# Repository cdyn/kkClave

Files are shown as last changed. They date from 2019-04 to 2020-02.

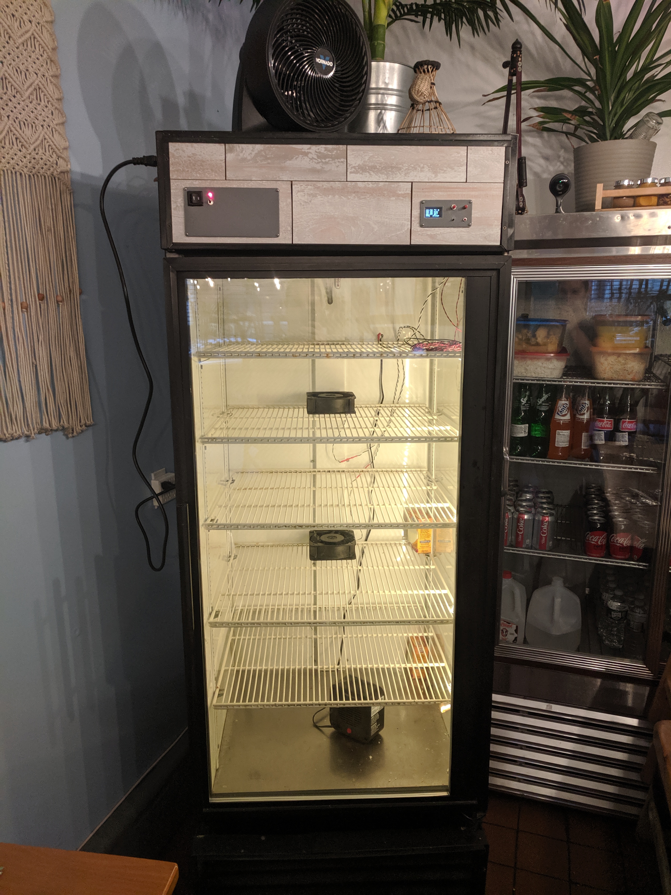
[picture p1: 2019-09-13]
images/kkClave_testFit.jpg

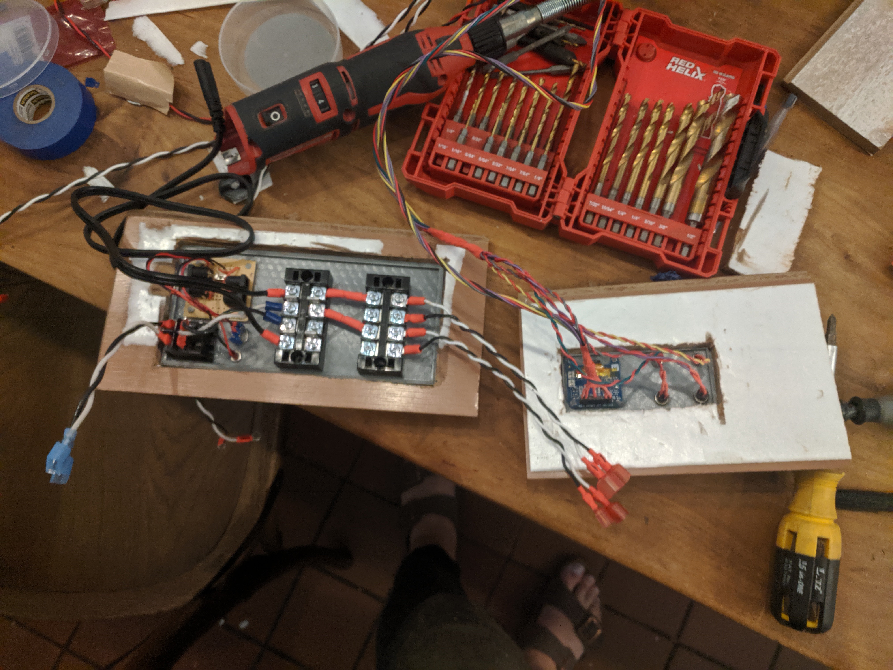
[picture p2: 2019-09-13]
images/kkClave_panels.jpg

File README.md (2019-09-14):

# kkClave ([wiki](https://github.com/cdyn/kkClave/wiki))
## [Korai Kitchen](https://www.koraikitchen.com/) Clave for yogurt incubation
#### Designed by [Jean Runnells](https://github.com/JERiv) @ [CDYN](https://github.com/cdyn)

This is a simple yougurt incubator that uses an arduino mega, a relay shield, and a space heater to make doi (yogurt) on a large scale in an upcycled beverege fridge. In this repository are: 
* [Fusion 360](../master/fusion) drawings for the power supply panel, the front panel, and an enclosure.
* [Eagle](../master/eagle) sketch of basic circuit diagram for logic and power supply including relevant shields
* [Arduino](../master/arduino) main program code

## See the [wiki](https://github.com/cdyn/kkClave/wiki) for installtion, fabrication, and use details.

## TODO:
*  implement ethernet
*  add cooling cycle features
*  handle clock overflow

[**Custom Dynamics**](https://www.customdyn.com) © [*GNU General Public License v3.0*](https://github.com/cdyn/kkClave/blob/master/LICENSE)

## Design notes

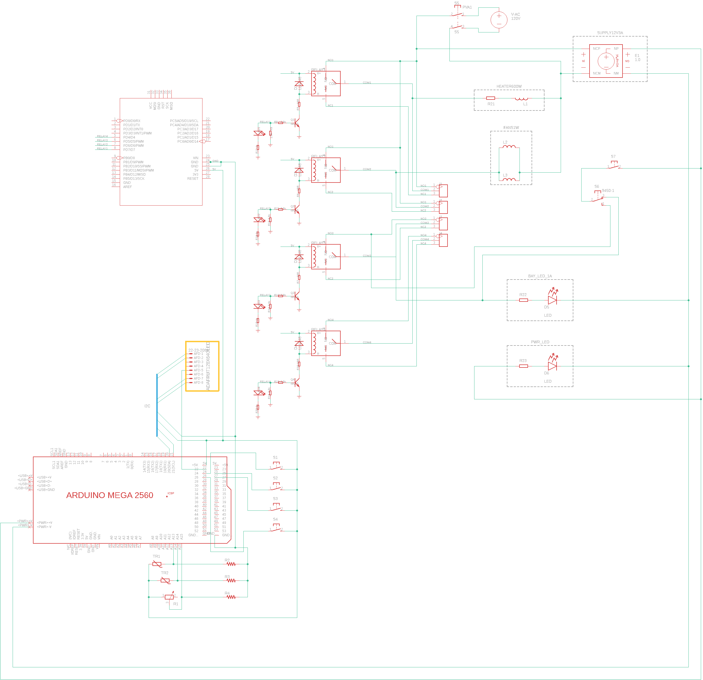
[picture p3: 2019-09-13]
images/kkClave_circuit.png

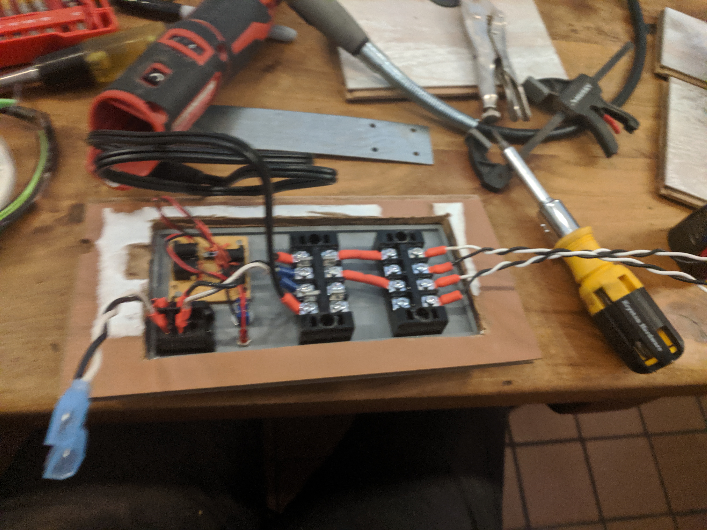
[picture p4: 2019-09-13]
images/kkClave_pwrPanel.jpg

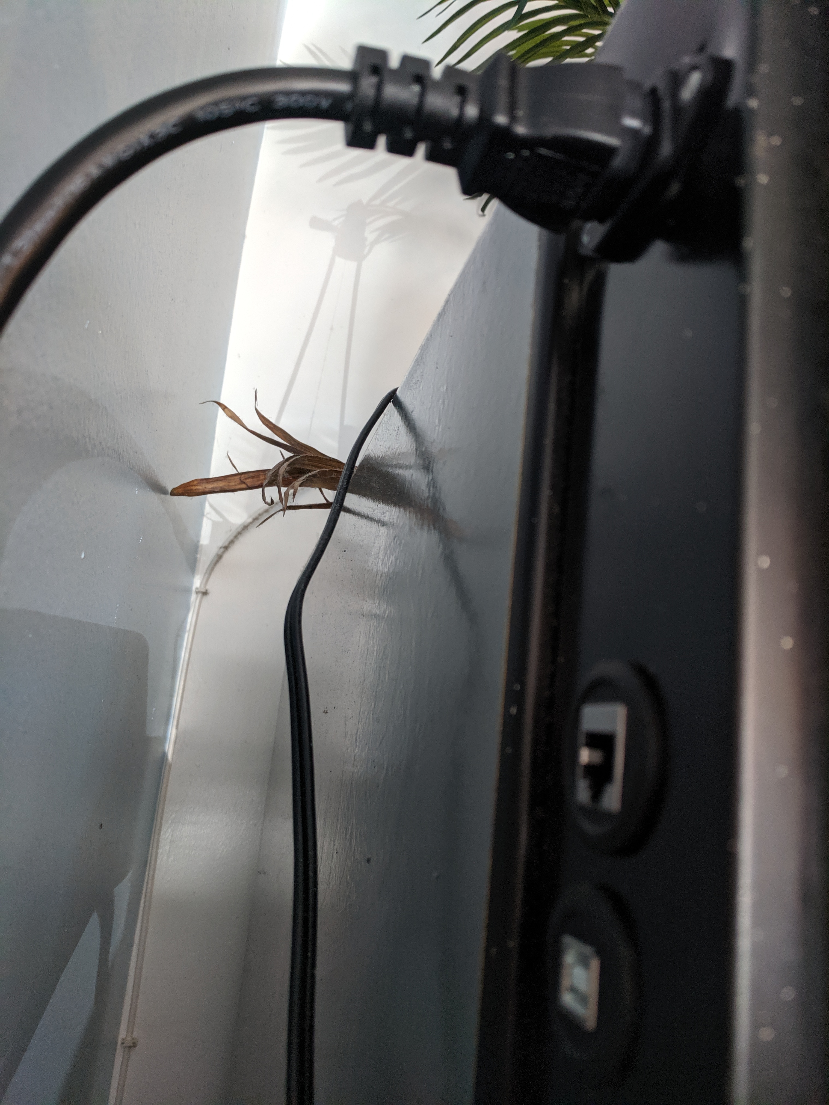
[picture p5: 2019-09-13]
images/kkClave_sidePlane.jpg

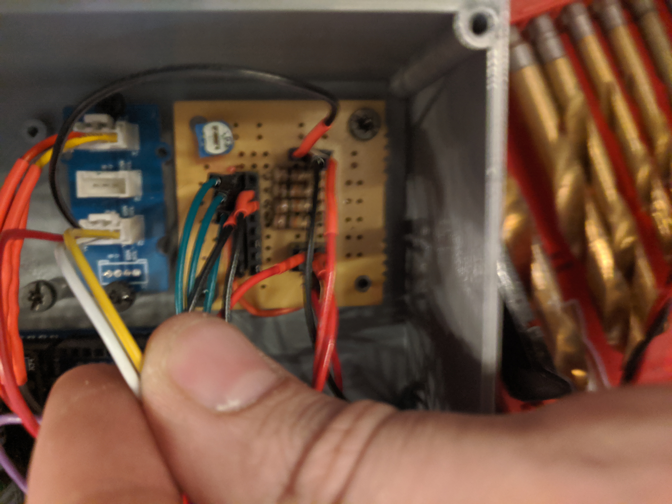
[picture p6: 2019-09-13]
images/kkClave_thermistorI2Cbreakout.jpg

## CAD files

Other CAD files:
fusion/kkClave_Front_Panel v1.f3d
fusion/kkClave_Logic_Enclosure.f3d
fusion/kkClave_Power_Panel v7.f3d

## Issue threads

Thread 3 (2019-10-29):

Logic reset

JERiv, 2019-10-29:
Leak through current from the ac supply is resetting the logic board particularly after the clave has warmed up, hopefully not heat and just requires a snubber to protect against transient voltage spikes

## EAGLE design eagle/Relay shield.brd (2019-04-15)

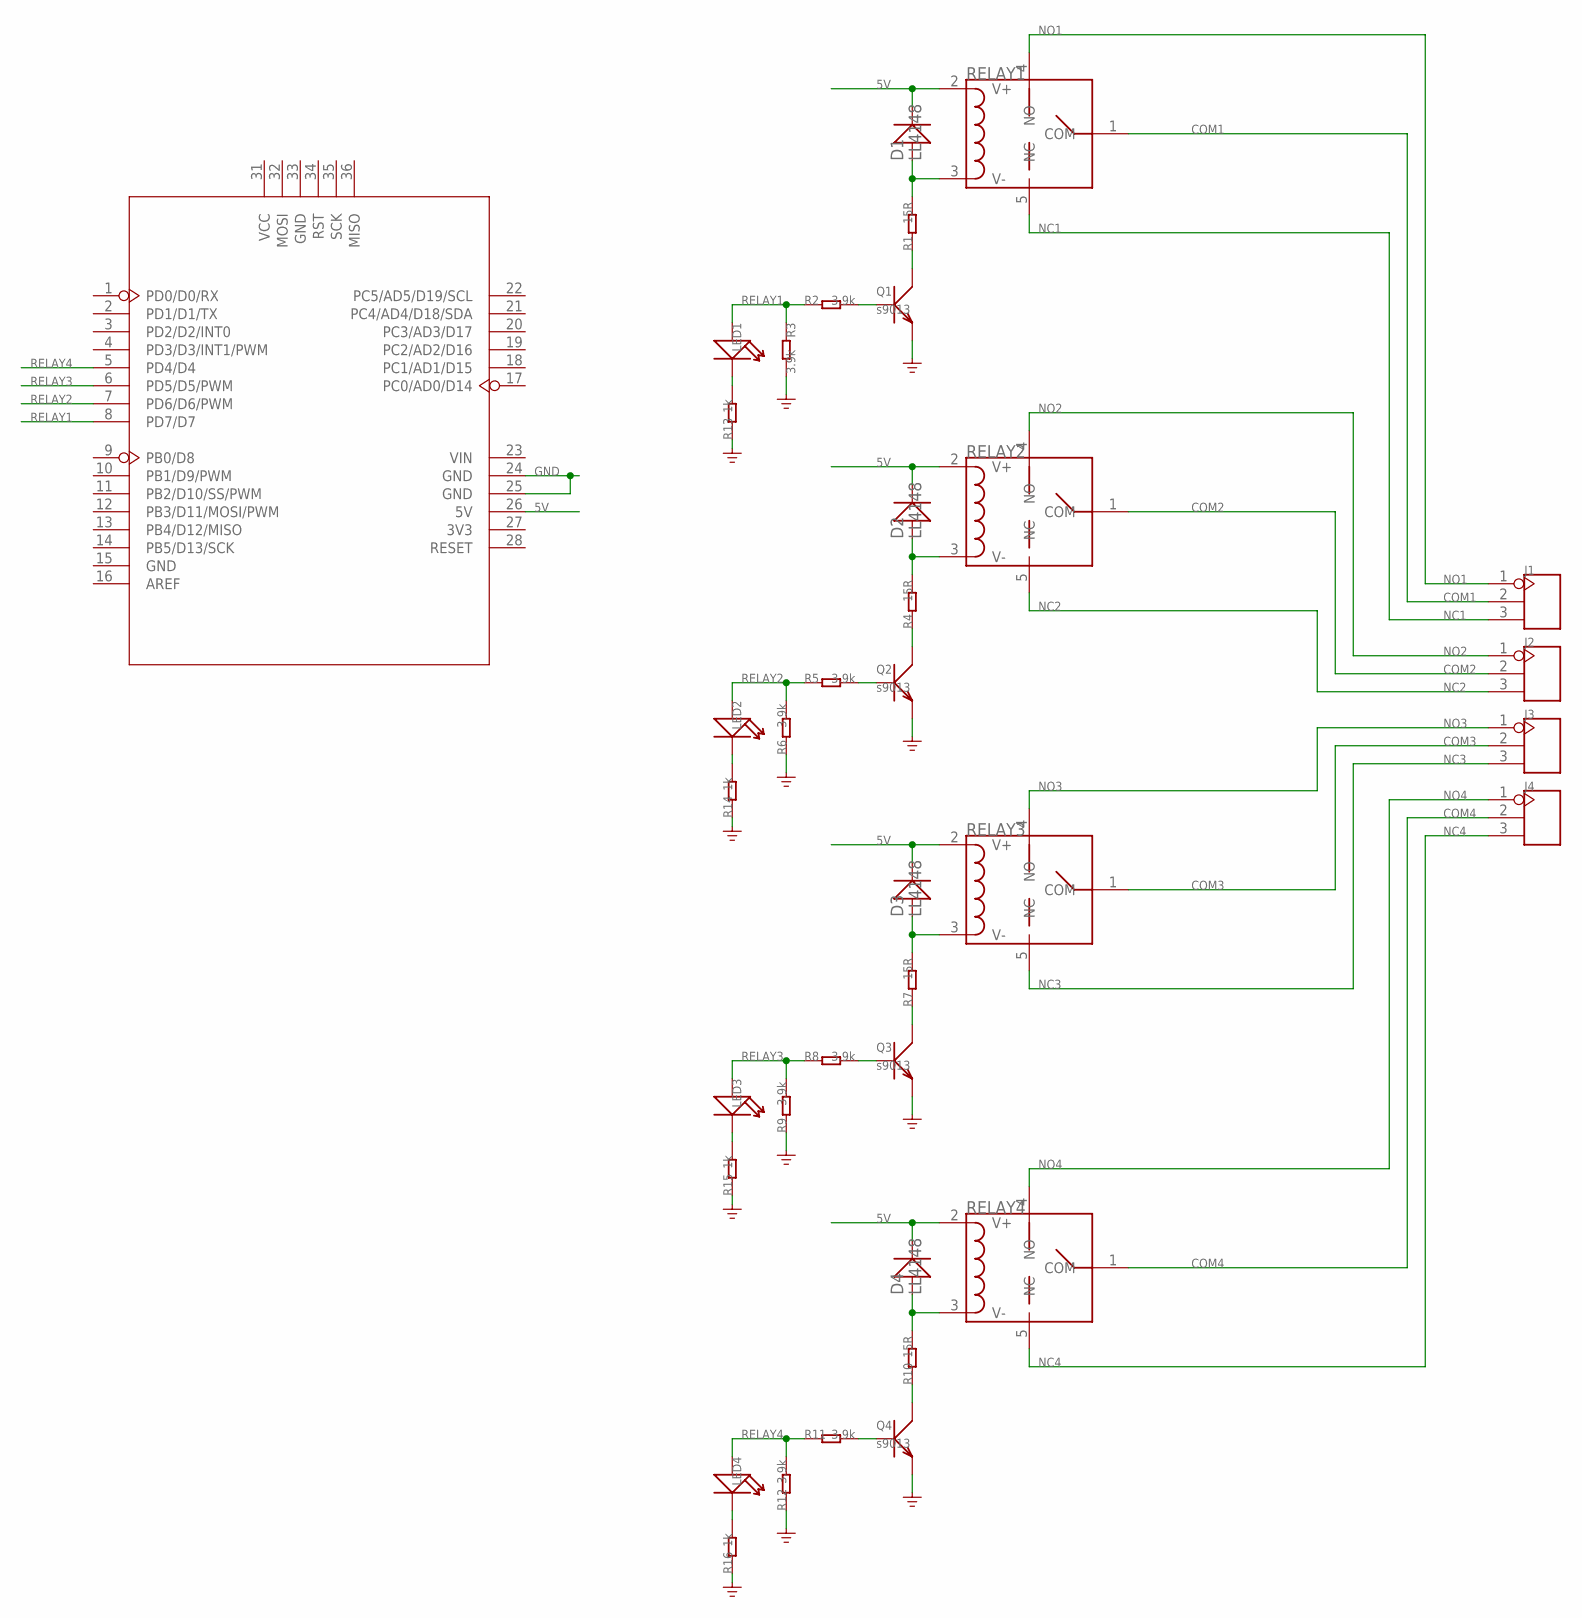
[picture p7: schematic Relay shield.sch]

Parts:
D1, D2, D3, D4: LL4148; D1206
J1, J2, J3, J4: SCREW-TERMINAL-3P'5.08'; 3P-5.08
LED1, LED2, LED3, LED4: LED'0603'; LED-0603
Q1, Q2, Q3, Q4: s9013; SOT23
R1, R4, R7, R10: 15R; R0603
R2, R3, R5, R6, R8, R9, R11, R12: 3.9k; R0603
R13, R14, R15, R16: 1k; R0603
RELAY1, RELAY2, RELAY3, RELAY4: RELAY-HLS8L-DC5V-S-C; 5P-19.0X15.5X15.8H
U1: ARDUINO'W/O-SILK'; ARDUINO-W/O-SILK

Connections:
5V: D1.-, D2.-, D3.-, D4.-, RELAY1.2 (V+), RELAY2.2 (V+), RELAY3.2 (V+), RELAY4.2 (V+), U1.26 (5V)
COM1: J1.2, RELAY1.1 (COM)
COM2: J2.2, RELAY2.1 (COM)
COM3: J3.2, RELAY3.1 (COM)
COM4: J4.2, RELAY4.1 (COM)
GND: Q1.2 (E), Q2.2 (E), Q3.2 (E), Q4.2 (E), R3.2, R6.1, R9.1, R12.1, R13.1, R14.1, R15.1, R16.1, U1.24 (GND), U1.25 (GND)
unnamed: D2.+, R4.2, RELAY2.3 (V-)
unnamed: D3.+, R7.2, RELAY3.3 (V-)
unnamed: D4.+, R10.2, RELAY4.3 (V-)
unnamed: Q1.3 (C), R1.1
unnamed: Q2.3 (C), R4.1
unnamed: Q4.1 (B), R11.2
unnamed: D1.+, R1.2, RELAY1.3 (V-)
unnamed: Q3.3 (C), R7.1
unnamed: Q4.3 (C), R10.1
unnamed: Q3.1 (B), R8.2
unnamed: LED1.-, R13.2
unnamed: LED2.-, R14.2
unnamed: LED3.-, R15.2
unnamed: LED4.-, R16.2
unnamed: Q2.1 (B), R5.2
unnamed: Q1.1 (B), R2.2
NC1: J1.3, RELAY1.5 (NC)
NC2: J2.3, RELAY2.5 (NC)
NC3: J3.3, RELAY3.5 (NC)
NC4: J4.3, RELAY4.5 (NC)
NO1: J1.1, RELAY1.4 (NO)
NO2: J2.1, RELAY2.4 (NO)
NO3: J3.1, RELAY3.4 (NO)
NO4: J4.1, RELAY4.4 (NO)
RELAY1: LED1.+, R2.1, R3.1, U1.8 (PD7/D7)
RELAY2: LED2.+, R5.1, R6.2, U1.7 (PD6/D6/PWM)
RELAY3: LED3.+, R8.1, R9.2, U1.6 (PD5/D5/PWM)
RELAY4: LED4.+, R11.1, R12.2, U1.5 (PD4/D4)

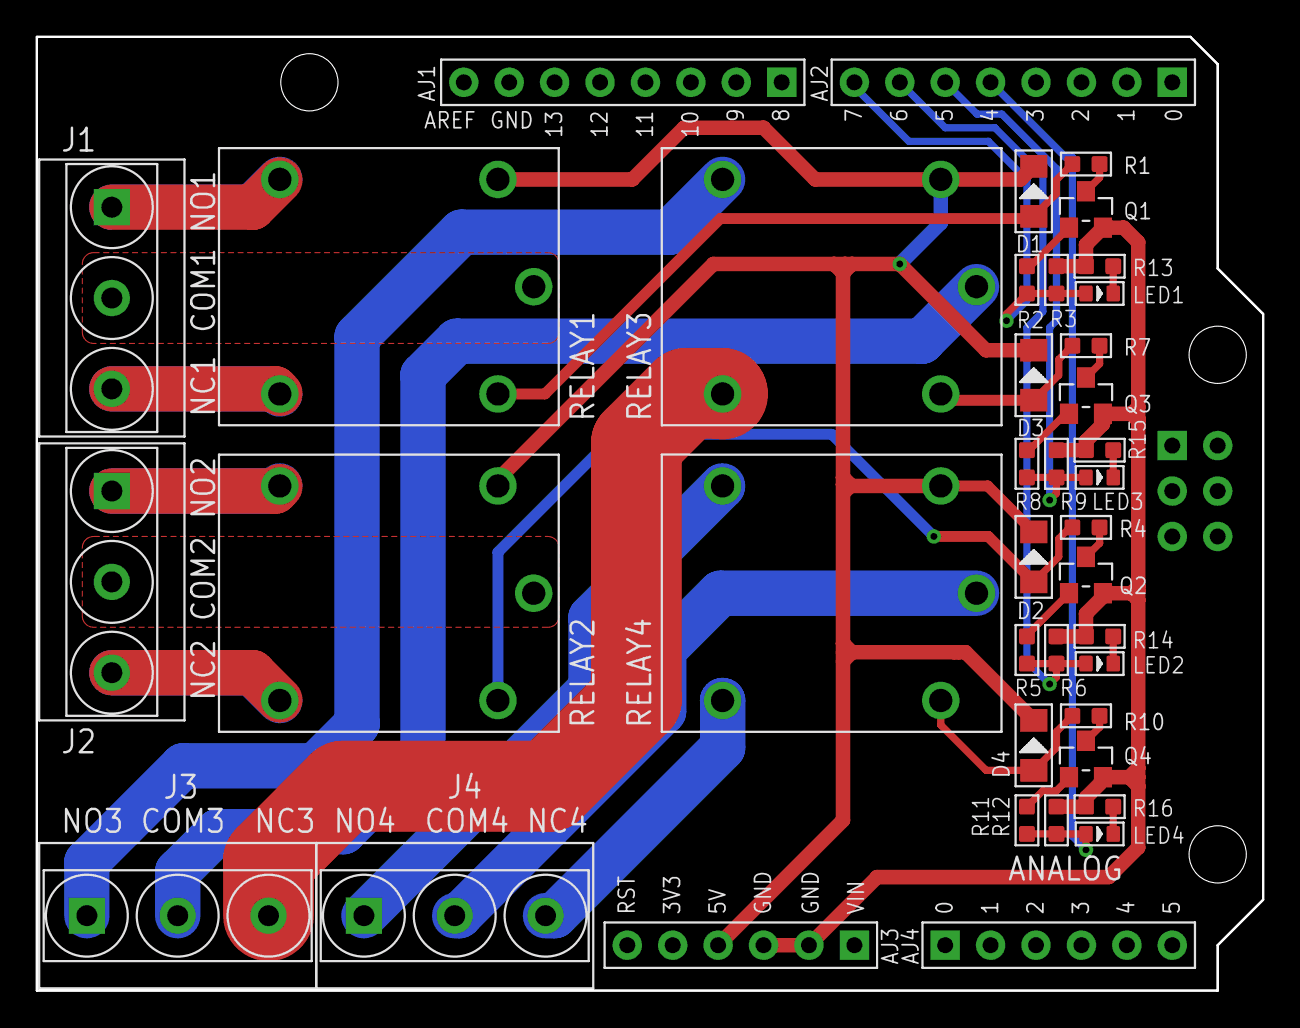
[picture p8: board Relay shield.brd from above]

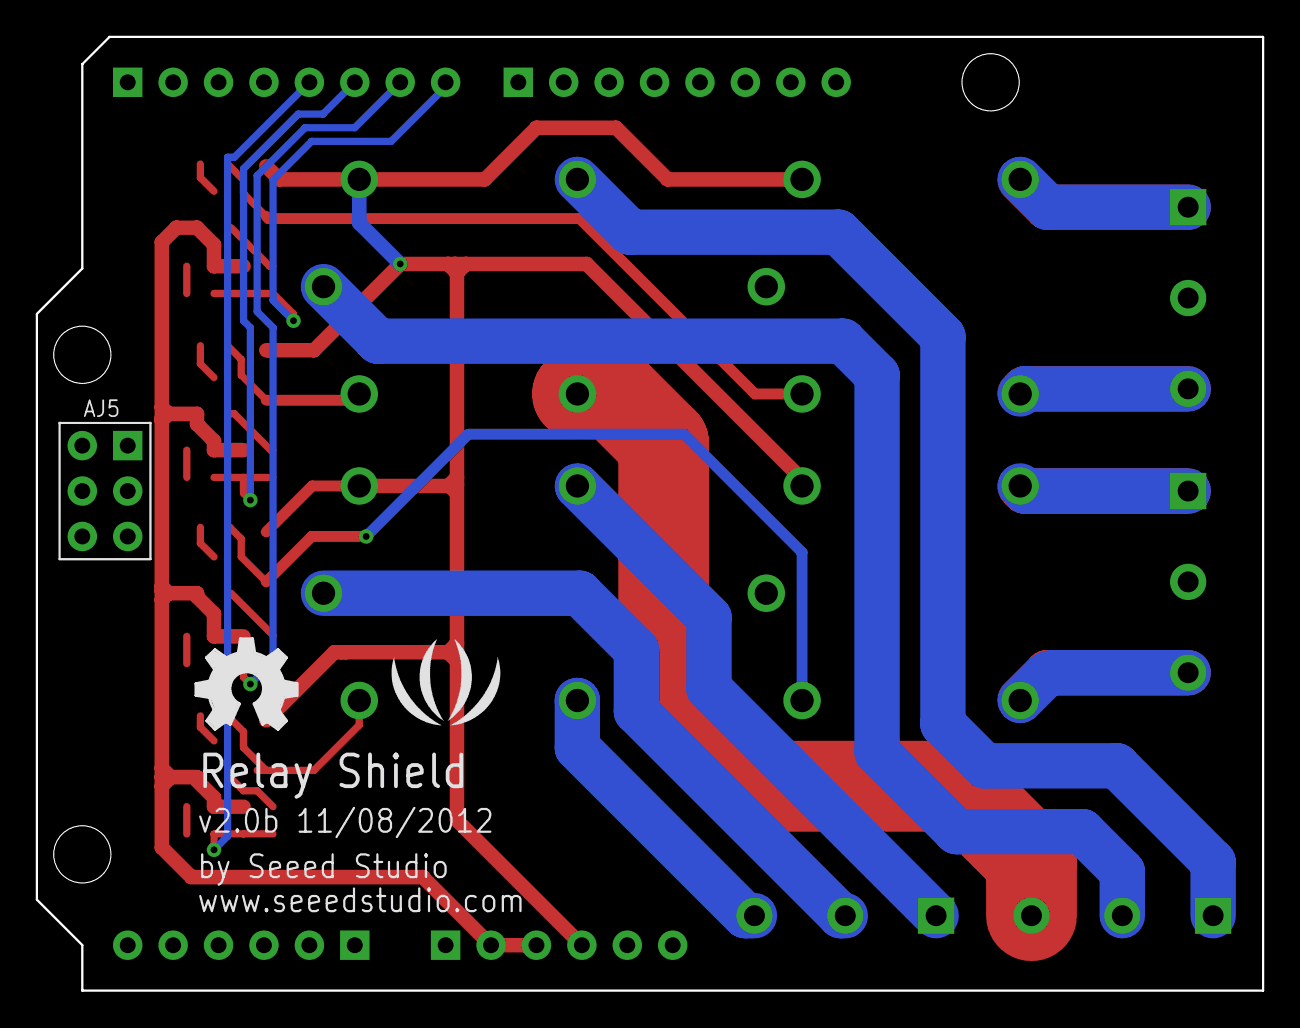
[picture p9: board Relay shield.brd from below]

Board: 2 copper layers, 68.6 x 53.3 mm, 39 parts (2 on the bottom side), 34 nets.

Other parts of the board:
U$13: LOGO_SILK
U$14: OSHW_FILLX200_NOTEXT

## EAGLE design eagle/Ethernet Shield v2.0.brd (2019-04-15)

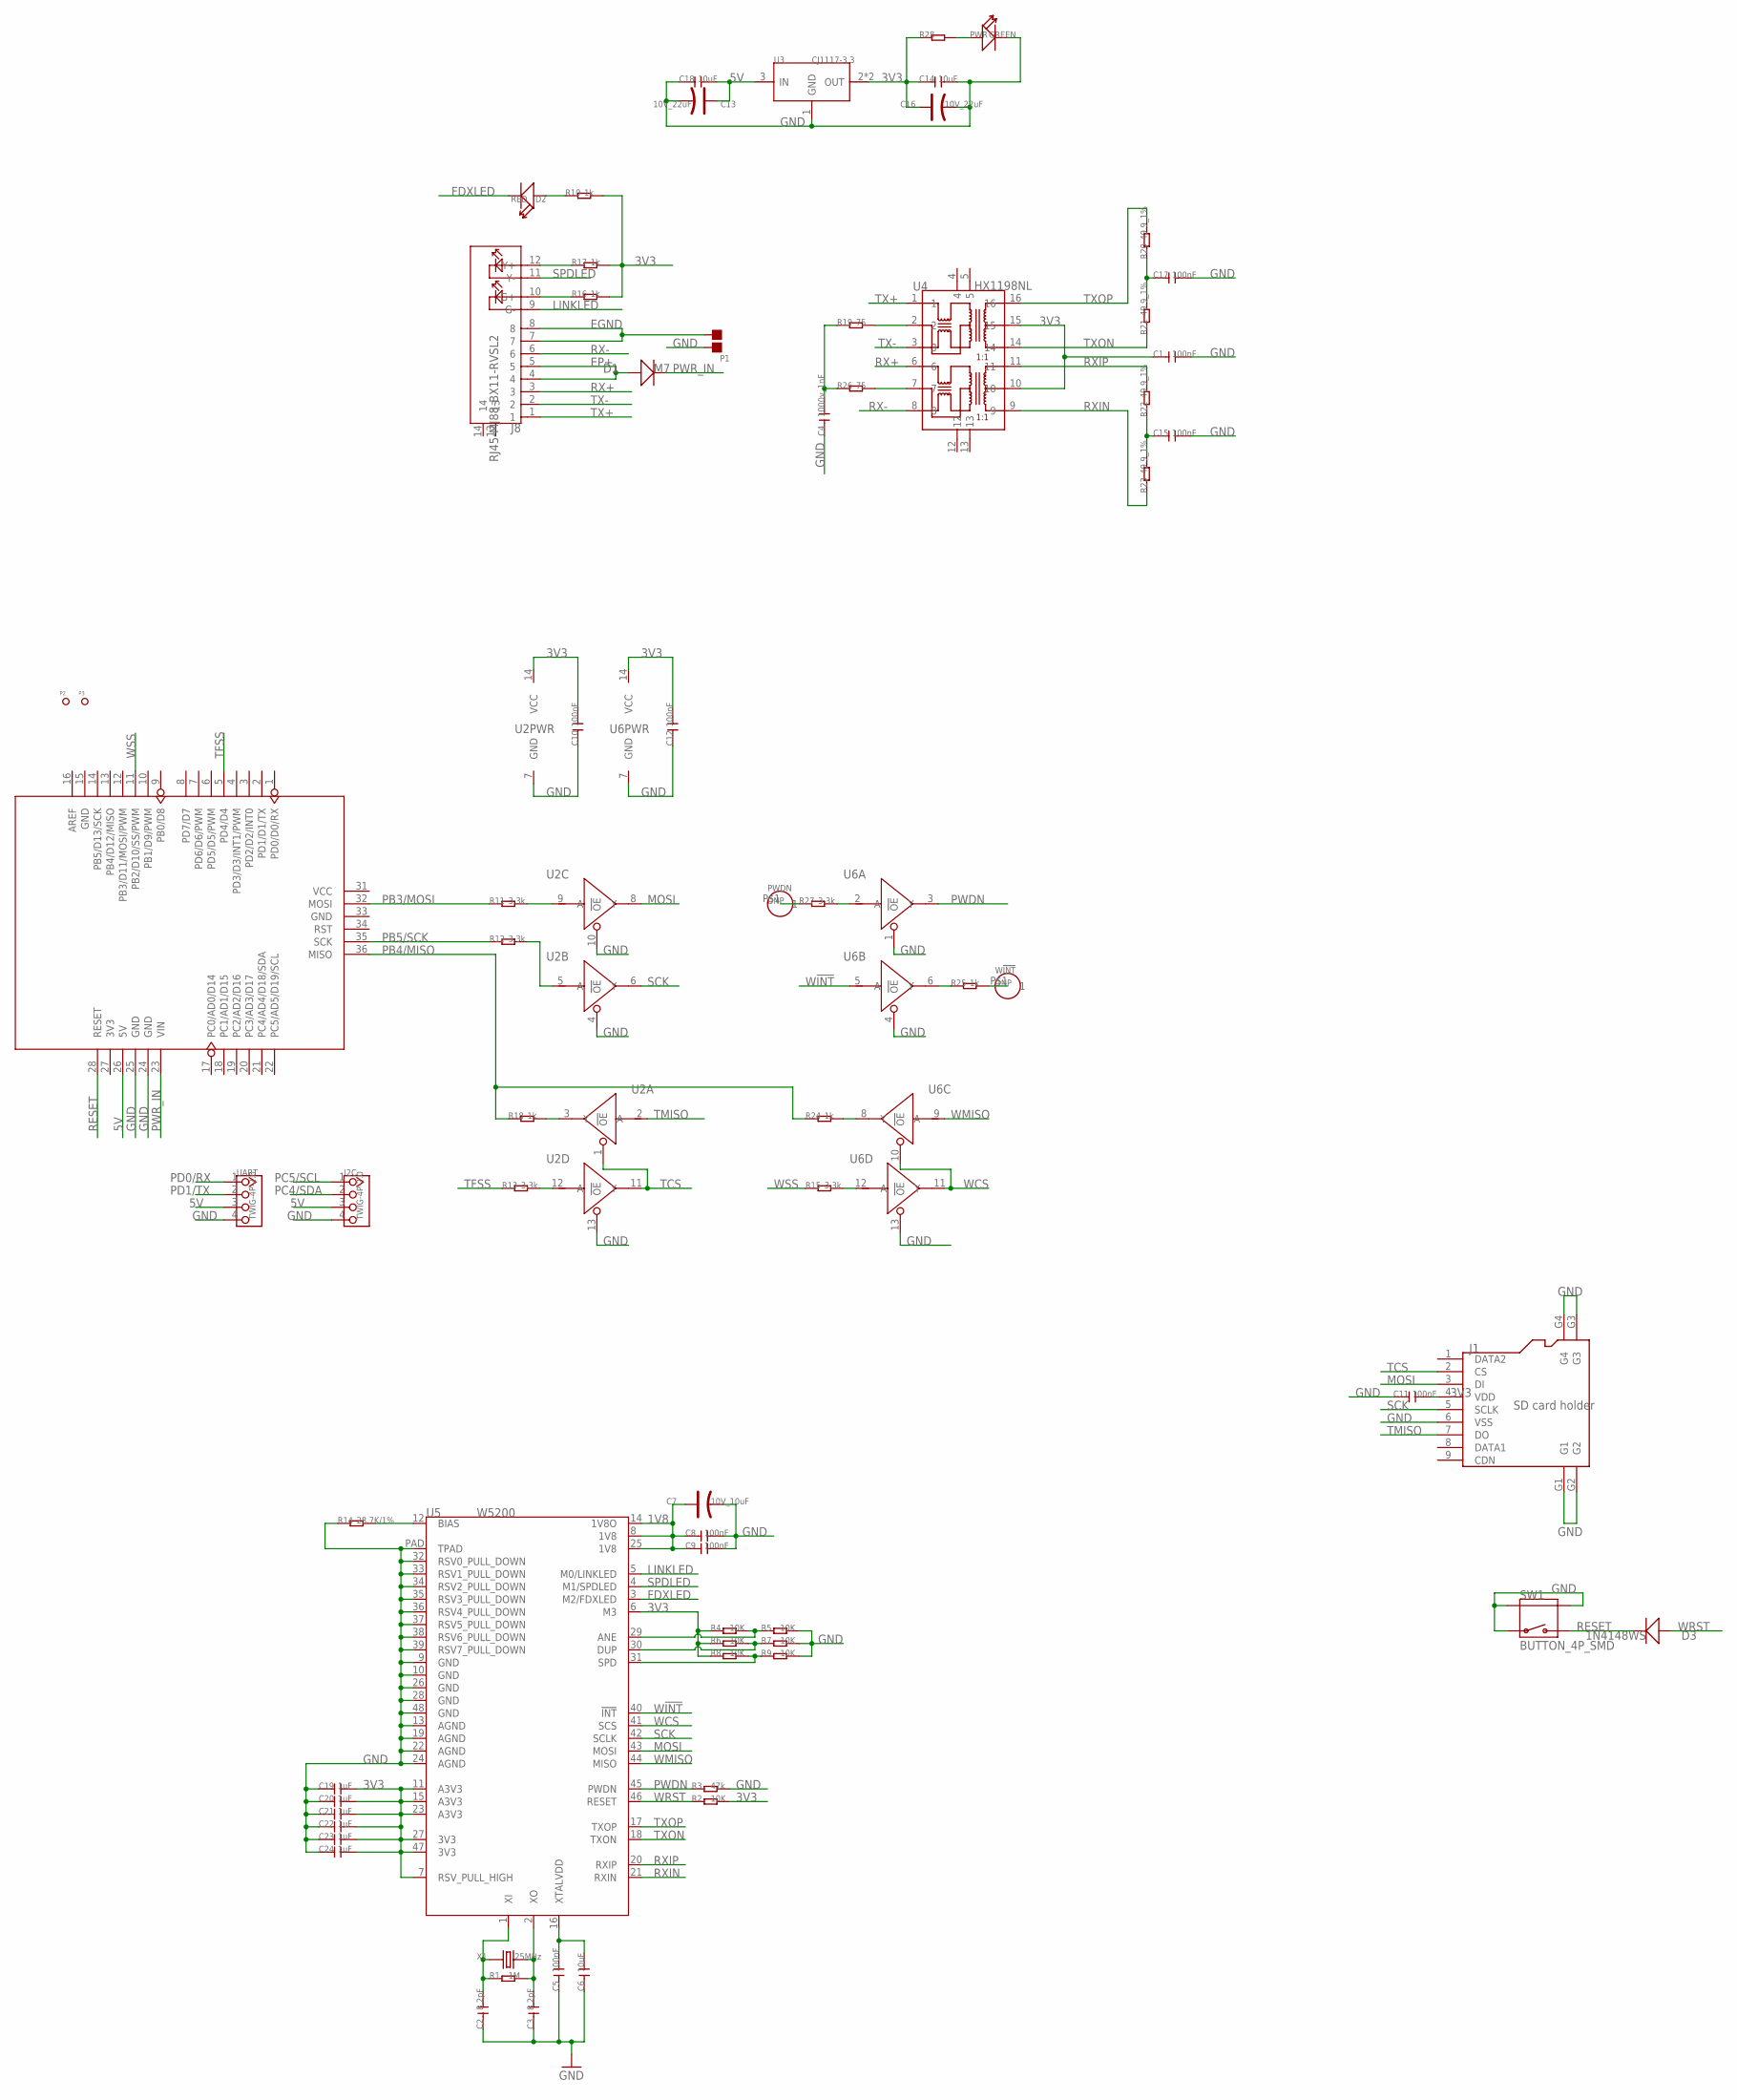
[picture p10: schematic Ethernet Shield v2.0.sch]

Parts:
C1, C5, C8, C9, C10, C11, C12, C15, C17: 100nF; C0603
C2, C3: 8.2pF; C0603
C4: 1000v_1nF; C1206
C6, C14, C18: 10uF; C0805
C7: 10V_10uF; AVX-A
C13, C16: 10V_22uF; AVX-B
C19, C20, C21, C22, C23, C24: 1uF; C0805
D1: M7; D2010
D2: RED; LED-0603
D3: 1N4148WS; SOD323
I2C: TWIG-4P-2.0; 4P-2.0
J1: SD card holder; 9P-SMD-W/-RING
J8: RJ45-MJ88-BX11-RVSL2
P1: DNP; 2P-SMD-1.78X1.27
P2, P3: PAD-MARK; ROUND-MARK-1.0
PWDN: DNP; 1P-65/35MIL
PWR: GREEN; LED-0603
R1: 1M; R0603
R2, R4, R5, R6, R7, R8, R9: 10K; R0603
R3: 47k; R0603
R10, R16, R17, R18, R24, R25: 1k; R0603
R11, R12, R13, R15, R27: 3.3k; R0603
R14: 28.7K/1%; R0603
R19, R26: 75; R0603
R20, R21, R22, R23: 49.9_1%; R0603
R28: R-0603; R0603
SW1: BUTTON_4P_SMD; 4P-SMD-7X3.5X3.5
U1: ARDUINO
U2, U6: 74VHC125PW; TSSOP14
U3: CJ1117-3.3; SOT-223
U4: HX1198NL; SOIC16-9.53
U5: W5200; QFN48
UART: TWIG-4P-2.0; 4P-2.0
W!INT: DNP; 1P-65/35MIL
X1: 25MHz; 2P-SMD-5X3.2

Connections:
1V8: C7.+, C8.1, C9.1, U5.8 (1V8), U5.14 (1V8O), U5.25 (1V8)
3V3: C1.1, C10.2, C11.2, C12.2, C14.1, C16.+, C19.2, C20.2, C21.2, C22.2, C23.2, C24.2, J1.4 (VDD), R2.2, R4.1, R6.1, R8.1, R10.2, R16.2, R17.2, R28.1, U2.14 (VCC), U3.2 (OUT), U3.TER (OUT), U4.10, U4.15, U5.6 (M3), U5.7 (RSV_PULL_HIGH), U5.11 (A3V3), U5.15 (A3V3), U5.23 (A3V3), U5.27 (3V3), U5.47 (3V3), U6.14 (VCC)
5V: C13.+, C18.2, I2C.3, U1.26 (5V), U3.3 (IN), UART.3
EGND: J8.7, J8.8, P1.1
EP+: D1.+, J8.4, J8.5
FDXLED: D2.-, U5.3 (M2/FDXLED)
GND: C1.2, C2.1, C3.1, C4.1, C5.1, C6.1, C7.-, C8.2, C9.2, C10.1, C11.1, C12.1, C13.-, C14.2, C15.2, C16.-, C17.2, C18.1, C19.1, C20.1, C21.1, C22.1, C23.1, C24.1, I2C.4, J1.6 (VSS), J1.G1, J1.G2, J1.G3, J1.G4, P1.2, PWR.-, R3.2, R5.2, R7.2, R9.2, R14.1, SW1.1, SW1.S1, SW1.S2, U1.24 (GND), U1.25 (GND), U2.4 (!OE), U2.7 (GND), U2.10 (!OE), U2.13 (!OE), U3.1 (GND), U5.9 (GND), U5.10 (GND), U5.13 (AGND), U5.19 (AGND), U5.22 (AGND), U5.24 (AGND), U5.26 (GND), U5.28 (GND), U5.32 (RSV0_PULL_DOWN), U5.33 (RSV1_PULL_DOWN), U5.34 (RSV2_PULL_DOWN), U5.35 (RSV3_PULL_DOWN), U5.36 (RSV4_PULL_DOWN), U5.37 (RSV5_PULL_DOWN), U5.38 (RSV6_PULL_DOWN), U5.39 (RSV7_PULL_DOWN), U5.48 (GND), U5.PAD (TPAD), U6.1 (!OE), U6.4 (!OE), U6.7 (GND), U6.13 (!OE), UART.4
LINKLED: J8.9 (G-), U5.5 (M0/LINKLED)
MOSI: J1.3 (DI), U2.8 (Y), U5.43 (MOSI)
unnamed: C2.2, R1.1, U5.1 (XI), X1.1
unnamed: C3.2, R1.2, U5.2 (XO), X1.2
unnamed: R4.2, R5.1, U5.29 (ANE)
unnamed: R6.2, R7.1, U5.30 (DUP)
unnamed: R8.2, R9.1, U5.31 (SPD)
unnamed: D2.+, R10.1
unnamed: R12.2, U2.5 (A)
unnamed: R11.2, U2.9 (A)
unnamed: R13.2, U2.12 (A)
unnamed: R15.2, U6.12 (A)
unnamed: R26.2, U4.7
unnamed: R19.2, U4.2
unnamed: C4.2, R19.1, R26.1
unnamed: R18.2, U2.3 (Y)
unnamed: C15.1, R22.1, R23.2
unnamed: C17.1, R20.1, R21.2
unnamed: R24.2, U6.8 (Y)
unnamed: J8.12 (Y+), R17.1
unnamed: J8.10 (G+), R16.1
unnamed: R25.1, U6.6 (Y)
unnamed: R25.2, W!INT.P$1
unnamed: C5.2, C6.2, U5.16 (XTALVDD)
unnamed: R14.2, U5.12 (BIAS)
unnamed: R27.2, U6.2 (A)
unnamed: PWDN.P$1, R27.1
unnamed: PWR.+, R28.2
PB3/MOSI: R11.1, U1.32 (MOSI)
PB4/MISO: R18.1, R24.1, U1.36 (MISO)
PB5/SCK: R12.1, U1.35 (SCK)
PC4/SDA: I2C.2
PC5/SCL: I2C.1
PD0/RX: UART.1
PD1/TX: UART.2
PWDN: R3.1, U5.45 (PWDN), U6.3 (Y)
PWR_IN: D1.-, U1.23 (VIN)
RESET: D3.-, SW1.2, U1.28 (RESET)
RX+: J8.3, U4.6
RX-: J8.6, U4.8
RXIN: R23.1, U4.9, U5.21 (RXIN)
RXIP: R22.2, U4.11, U5.20 (RXIP)
SCK: J1.5 (SCLK), U2.6 (Y), U5.42 (SCLK)
SPDLED: J8.11 (Y-), U5.4 (M1/SPDLED)
TCS: J1.2 (CS), U2.1 (!OE), U2.11 (Y)
TFSS: R13.1, U1.5 (PD4/D4)
TMISO: J1.7 (DO), U2.2 (A)
TX+: J8.1, U4.1
TX-: J8.2, U4.3
TXON: R21.1, U4.14, U5.18 (TXON)
TXOP: R20.2, U4.16, U5.17 (TXOP)
W!INT: U5.40 (!INT), U6.5 (A)
WCS: U5.41 (SCS), U6.10 (!OE), U6.11 (Y)
WMISO: U5.44 (MISO), U6.9 (A)
WRST: D3.+, R2.1, U5.46 (RESET)
WSS: R15.1, U1.11 (PB2/D10/SS/PWM)

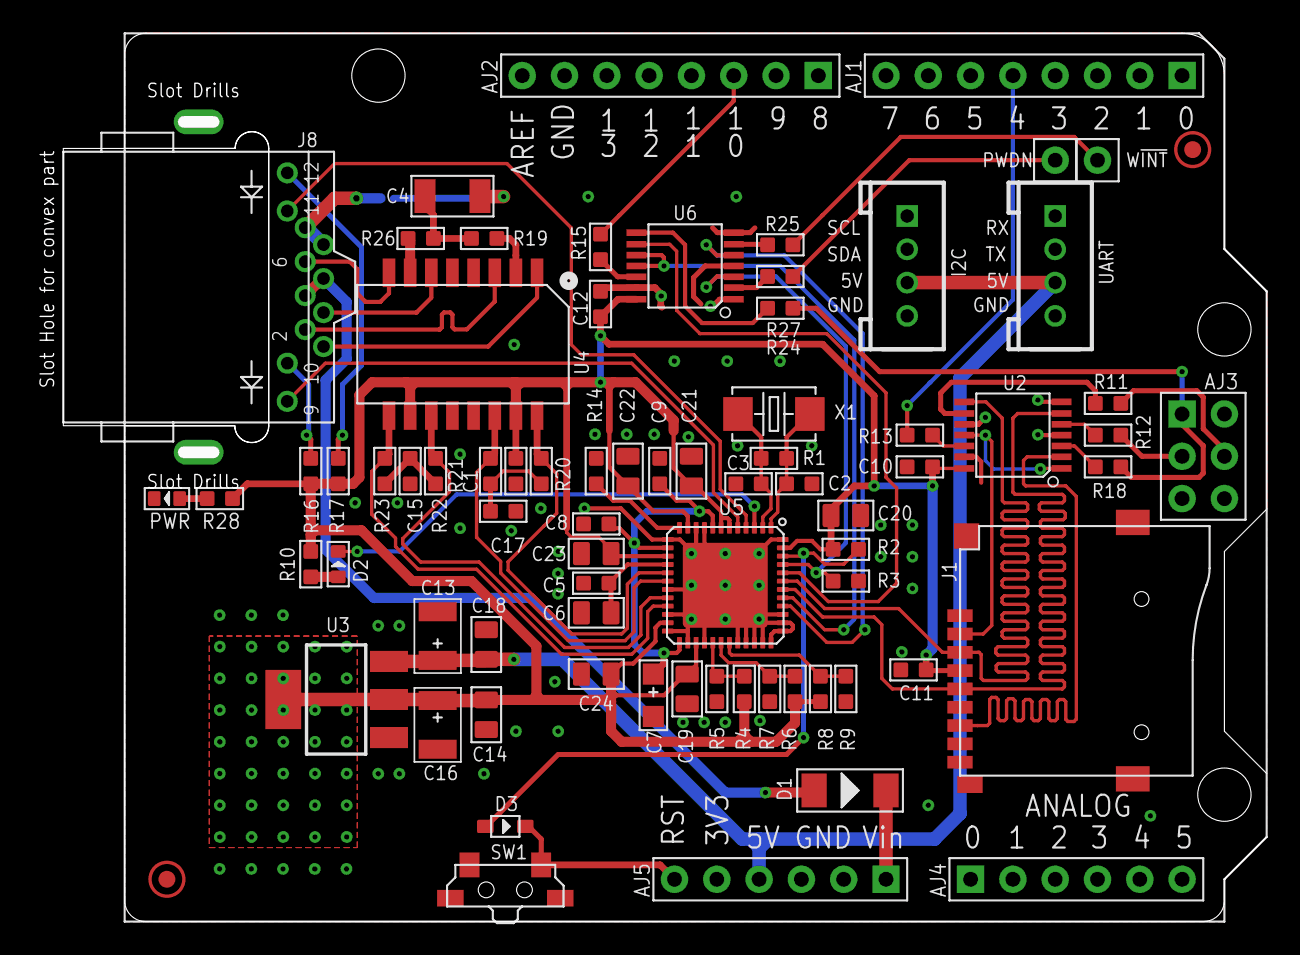
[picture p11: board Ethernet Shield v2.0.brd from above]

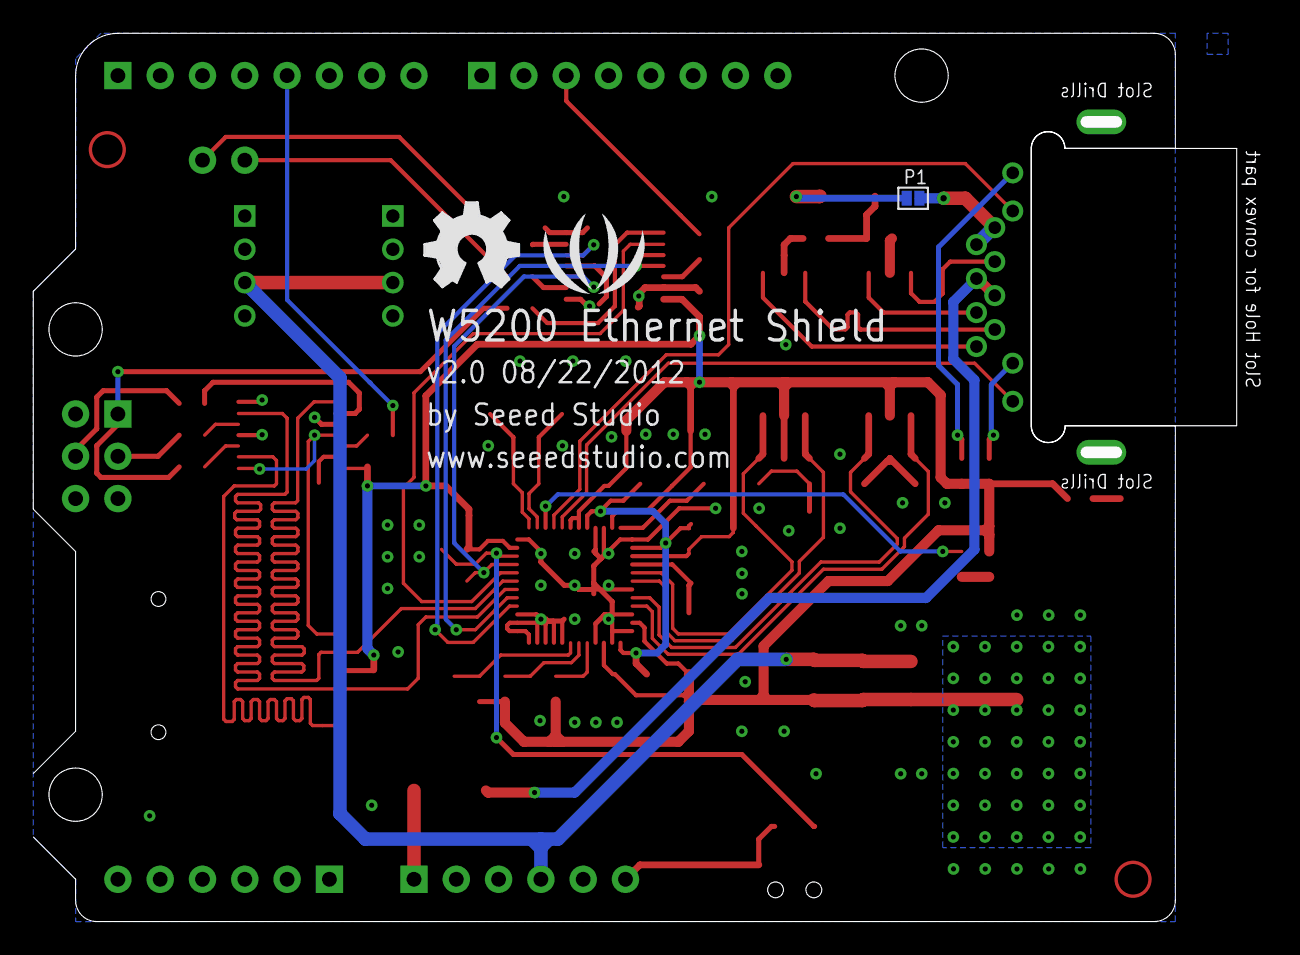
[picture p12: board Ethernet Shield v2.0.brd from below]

Board: 2 copper layers, 72.3 x 53.3 mm, 75 parts (3 on the bottom side), 59 nets.

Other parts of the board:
U$1: LOGO_SILK
U$2: OSHW_FILLX200_NOTEXT

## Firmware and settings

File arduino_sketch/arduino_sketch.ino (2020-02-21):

/*
 * kkClave
 *    Upcycled Yogurt incubator: assumes arduino mega 2560, relay
 *    shield, ethernet shield, Adafruit_SSD1306 on i2c
 * https://github.com/cdyn/kkClave
 *
 * Jean Runnells
 * https://www.customdyn.com
 *
 * GNU General Public License v3.0
 * https://github.com/cdyn/kkClave/blob/master/LICENSE
 *
 * @todo
 *  - implement ethernet
 *  - add cooling cycle features
 *  - handle clock overflow
 *  - add runtime max
 *  - workaround verbose thermistor
 */

#include <SPI.h>
#include <Wire.h>
#include <Ethernet.h>
#include <SD.h>
#include <Adafruit_GFX.h>
#include <Adafruit_SSD1306.h>
#include <thermistor.h>

// Override verbose serial output from thermistor library
#ifdef VERBOSE_SENSOR_ENABLED 
#undef VERBOSE_SENSOR_ENABLED 
#define VERBOSE_SENSOR_ENABLED 0
#endif

// Declarations for an SSD1306 display connected to I2C (SDA, SCL pins) 
#define SCREEN_WIDTH 128 ///< OLED display width, in pixels
#define SCREEN_HEIGHT 64 ///< OLED display height, in pixels
#define OLED_RESET 22 ///< Reset pin # (4)(or -1 if sharing Arduino reset pin)
Adafruit_SSD1306 display(SCREEN_WIDTH, SCREEN_HEIGHT, &Wire, OLED_RESET);
#define NUMFLAKES     10 ///< Number of snowflakes in the animation example
#define LOGO_HEIGHT   16 ///< Animation logo height
#define LOGO_WIDTH    16 ///< Animation logo width
#define XPOS   0
#define YPOS   1
#define DELTAY 2
static const unsigned char PROGMEM logo_bmp[] =
{ B00000000, B11000000,
  B00000001, B11000000,
  B00000001, B11000000,
  B00000011, B11100000,
  B11110011, B11100000,
  B11111110, B11111000,
  B01111110, B11111111,
  B00110011, B10011111,
  B00011111, B11111100,
  B00001101, B01110000,
  B00011011, B10100000,
  B00111111, B11100000,
  B00111111, B11110000,
  B01111100, B11110000,
  B01110000, B01110000,
  B00000000, B00110000 };

//pin addresses
static const int PROGMEM t0_a = A13;
static const int PROGMEM t1_a = A14;
static const int PROGMEM c0_a = A15;
static const int PROGMEM r1_d = 4;//old 5
static const int PROGMEM r2_d = 6;
static const int PROGMEM r3_d = 7;
static const int PROGMEM s0_d = 24;
static const int PROGMEM s1_d = 25;
static const int PROGMEM s2_d = 26;
static const int PROGMEM s3_d = 27;

//IO states
THERMISTOR t0(t0_a,        // Analog pin
              10000,       // Nominal resistance at 25 ºC
              3950,        // thermistor's beta coefficient
              10000);      // Value of the series resistor
THERMISTOR t1(t1_a,        // Analog pin
              10000,       // Nominal resistance at 25 ºC
              3950,        // thermistor's beta coefficient
              10000);      // Value of the series resistor
int _t0 = 0; ///< themistor0 1/10 ºC
int _t1 = 0; ///< themistor1 1/10 ºC
int c0 = 0; ///< potentiometer (unused)
int s0 = 0; ///< start button
int s1 = 0; ///< mode button
int s2 = 0; ///< add button
int s3 = 0; ///< dec button
bool r1 = 0; ///< heater relay
bool r2 = 0; ///< fan realy
bool r3 = 0; ///< light realy

//LOGIC vars
int start = 0; ///< cycle state: 0=ProgSet 1=ProgRun 2=ProgFin
int mode = 0; ///< input state: 0=TempSet 1=TimeSet
float temp = 0; ///< ºC computed temp
float set_temp = 50; ///< ºC default set temp
float heat_thresh = 2; ///< ºC +- threshold for heater start/stop i.e. 'swing'
float fan_thresh = 6; ///< ºC thermometer diff threshold for fan start/stop
unsigned long run_time = 21600000; ///< default runtime (6 hr)
unsigned long inc = 300000; ///< inc/dec minimum time increment (5 min)
unsigned long start_time = 0; ///< cycle start time
unsigned long end_time = 0; ///< cycle end time
unsigned long stby = millis(); ///< last press for screensaver and race, if 0 device is in standby
unsigned long race_hold = 500; ///< inc/dec race delay

/**
 * Arduino init
 */
void setup() {
  //start serial
  Serial.begin(9600);
  // SSD1306_SWITCHCAPVCC = generate display voltage from 3.3V internally
  if(!display.begin(SSD1306_SWITCHCAPVCC, 0x3D)) { // Address 0x3D for 128x64
    Serial.println(F("SSD1306 allocation failed"));
    for(;;); // Don't proceed, loop forever
  }

  // Show initial display buffer contents on the screen --
  // the library initializes this with an Adafruit splash screen.
  display.display();
  delay(2000); // Pause for 2 seconds
  // Digital pin mode
  pinMode(r1_d, OUTPUT);
  pinMode(r2_d, OUTPUT);
  pinMode(r3_d, OUTPUT);
  pinMode(s0_d, INPUT_PULLUP);
  pinMode(s1_d, INPUT_PULLUP);
  pinMode(s2_d, INPUT_PULLUP);
  pinMode(s3_d, INPUT_PULLUP);
  // Clear the buffer
  display.clearDisplay();
  //testanimate(logo_bmp, LOGO_WIDTH, LOGO_HEIGHT);
}

/**
 * Cycle set and chron handler, launches screen saver
 */
void stop() { // Cycle set code and cron handler
  if ( start == 0 ) { // cycle start: launch screen saver after delay
    if(millis() > stby + 300000){ // screen saver delay (5 min)
      stby = 0;
      relay();
      testanimate(logo_bmp, LOGO_WIDTH, LOGO_HEIGHT);
    }
  } else if ( start == 1 ){ // cycle run:  run until end_time
    if (millis() > end_time) { start = 2; }
  } else if (start == 2){ // cycle fin: lanunch screensaver after cooldown
    if(millis() > end_time + 900000 && millis() > stby + 300000){ // screen saver after cooldown (15 min)
      stby = 0;
      relay();
      testanimate(logo_bmp, LOGO_WIDTH, LOGO_HEIGHT);
    }
  }
  else {

  }
  //delay(100); //uncomment to slow down serial output
}

/**
 * Poll sensors and buttons, do any resultant calculations
 */
void poll() {
  //read sensors
  c0 =  analogRead(c0_a);
  s0 =  digitalRead(s0_d);
  s1 =  digitalRead(s1_d);
  s2 =  digitalRead(s2_d);
  s3 =  digitalRead(s3_d);
  _t0 = t0.read();
  _t1 = t1.read();
  temp = (_t0 + _t1) / 20.0;
  //button handlers
  if(s0 == LOW){//Start button
    if(stby == 0){//wake from standby
      stby = millis();
      while(digitalRead(s0_d) == LOW){}
      return;
    }
    if(start == 0) {
      start = 1;
      start_time = millis();
      end_time = millis() + run_time;
    } else if(start == 1) {
      start = 2;
      end_time = millis();
    }
    else if(start == 2) {
      start = 0;
      end_time = 0;
      start_time = 0;
    }
    else if(start == 3) {
      start = 0;
    }
    else {
      start = 0;
      end_time = 0;
      start_time = 0;
    }
    printState();
    stby = millis();
    while(digitalRead(s0_d) == LOW){}
  }
  if(s1 == LOW){//mode button
    if(stby == 0){//wake from standby
      stby = millis();
      while(digitalRead(s1_d) == LOW){}
      return;
    }
    int mset = 0;
    if (mode == 0) {
      mset = 1;
    } else if (mode == 1){
      mset = 0;
    } else {mset = 0;}
    mode = mset;
    printState();
    stby = millis();
    while(digitalRead(s1_d) == LOW){}
  }
  if(s2 == LOW){//increment with hold down race
    if(stby == 0){//wake from standby
      stby = millis();
      while(digitalRead(s2_d) == LOW){}
      return;
    }
    if(mode == 0) {
      set_temp += 1;
    } else if(mode == 1){
      run_time += inc;
      if (start == 1){end_time += inc;}
    }
    printState();
    stby = millis();
    while(digitalRead(s2_d) == LOW){//race on hold
      if(mode == 1 && millis() - stby > race_hold){
        stby = millis();
        run_time += inc * 3;
        if (start == 1){end_time += inc * 3;}
        printState();
      }
    }
  }
  if(s3 == LOW){//decrement with hold down race
    if(stby == 0){//wake from standby
      stby = millis();
      while(digitalRead(s0_d) == LOW){}
      return;
    }
    if(mode == 0) {
      set_temp -= 1;
    } else if(mode == 1){
      run_time -= inc;
      if (start == 1){end_time -= inc;}
    }
    printState();
    stby = millis();
    while(digitalRead(s3_d) == LOW){//race on hold
      if(mode == 1 && millis() - stby > race_hold){
        stby = millis();
        run_time -= inc * 3;
        if (start == 1){end_time -= inc * 3;}
        printState();
      }
    }
  }
}

/**
 * Change relay states based on cycle status and sensor feedback
 */
void relay() { // Update relay states
  float diff = (_t0 - _t1) / 10.0; //thermocouple temp difference in ºC
  Serial.println("diff:"+(String)diff+"  t0: " + (String)_t0 + "  t1:" + (String)_t1);
  if (start == 0){ //program unstart

    r1 = 0; // heater
    r2 = 0; // fan
    //light
    if (stby == 0){
      r3 = 0;
    } else {
      r3 = 1;
    }
  }
  else if (start == 1) { //program running
    // heater on/off with 'swing'
    if(r1 == 0 && temp < set_temp - heat_thresh){ r1 = 1; Serial.println("********Hot on********");}
    if(r1 == 1 && temp > set_temp + heat_thresh){ r1 = 0; Serial.println("********Hot off********");}
    // fan on/off with temp balance threshold
    if(r2 == 0 && abs(diff) > fan_thresh ){ r2 = 1; Serial.println("********Fan on********"); }
    if(r2 == 1 && abs(diff) < fan_thresh) { r2 = 0; Serial.println("********Fan off********");}
    //r3 = 1; // light
  }
  else if (start == 2){ //program finished
    r1 == 0;
    if (stby == 0){ //cooldwon elapsed, standby
      r2 = 0;
      r3 = 0;
    } else { //temp balance with fans during cooldown
      if(abs(diff) > fan_thresh ){ r2 = 1; }
      else { r2 = 0; }
      r3 = 1;
    }
  }
  else { // FAULT! saftey shut off ...
    r1 = 0;
    r2 = 0;
    r3 = 0;
  }

  //set relays - if relays get mixed around change assigment here
  if(r1) { digitalWrite(r1_d, HIGH); } else { digitalWrite(r1_d, LOW); }
  if(r2) { digitalWrite(r2_d, HIGH); } else { digitalWrite(r2_d, LOW); }
  //if(r1) { digitalWrite(r3_d, HIGH); } else { digitalWrite(r3_d, LOW); }
  //if(r1) { digitalWrite(4, HIGH); } else { digitalWrite(4, LOW); }
}

/**
 * Prints the current state to display and serial
 */
void printState() {
  //print state to serial
  Serial.println("c0:"+(String)c0);
  Serial.println("s0:"+(String)s0+" s1:"+(String)s1+" s2:"+(String)s2+" s3:"+(String)s3);
  Serial.println("r1:"+(String)r1+" r2:"+(String)r2+" r3:"+(String)r3);
  Serial.println("temp:"+(String)temp+" set_temp:"+(String)set_temp);
  Serial.println("time:"+(String)millis()+" end_time"+(String)end_time+" run_time:"+timeString(run_time));
  Serial.println("Status:"+statusString()+" Mode:"+ modeString()); 
  //print to display
  display.clearDisplay();
  display.setTextSize(2);      // Normal 1:1 pixel scale
  display.setTextColor(WHITE); // Draw white text
  display.setCursor(0, 0);     // Start at top-left corner
  display.cp437(true);         // Use full 256 char 'Code Page 437' font
  display.print((String)(int)temp + "/" + (String)(int)set_temp + " " + (char)248 + "C ");
  if(mode == 0) {display.print("*");}
  display.print("\n");
  if (start == 0 || start == 2) {
    display.print((String)"00:00 RUN\n" + timeString(run_time) + " SET");
  }
  else if (start == 1) {
    display.print(timeString(end_time-millis()) + " RUN\n" + timeString(run_time) + " SET");
  }
  if(mode == 1) {display.print("*");}
  display.print("\n");
  display.setTextSize(2);
  display.print(statusString() + "  " + modeString() + "\n");
  display.display();
}

/**
 * Returns a user readable string regrading the mode based on cycle state: temp/time based 
 * on mode and set/adujust based on cycle state
 * @retrun the current input mode
 */
String modeString() {
    if(start == 0) {
      if(mode == 0) {
        return "sTemp";
      } else if(mode == 1) {
        return "sTime";
      }
      else {return "ERR";}
  }
  else if(start == 1) {
    if(mode == 0) {
      return "aTemp";
    } else if(mode == 1) {
      return "aTime";
    }
    else {return "ERR";}
  }
  else if (start == 2) {
    return timeString(end_time-start_time);
  }
  else {return "ERR";}
}

/**
 * Prints a user readable hash code of the cycle status possible values returned
 * @return cycle status string
 */
String statusString() {
  if(start == 0) {
    return "PRG";
  }
  else if(start == 1) {
    return "RUN";
  }
  else if (start == 2) {
    return "FIN";
  }
  else {return "ERR"; }
}

/**
 * Stringifies an unsigned long representing milliseconcds to hours and minute format
 * @param t The time in ms
 * @return A String of the time in HH:MM format
 */
String timeString(unsigned long t) {
  unsigned long sec = t/1000;
  unsigned long _hour = sec / 3600;
  unsigned long _min = (sec % 3600)/60;
  //Serial.println((String)t+">"+(String)_hour+":"+(String)_min);
  char str[6];
  str[0] = '0' + _hour / 10;
  str[1] = '0' + _hour % 10;
  str[2] = ':';
  str[3] = '0' + _min / 10;
  str[4] = '0' + _min % 10;
  str[5] = '\0';
  return (String)str;
}

/**
 * This function will render a screen saver and call poll() to check for a button press this is a 
 * modified version of the adafruit sample function 
 * 
 * @param bitmap a bit map of the icon to be rendered, use logo_bmp
 * @param w logo width, use LOGO_WIDTH
 * @param h logo height, use LOGO_HEIGHT
 */
void testanimate(const uint8_t *bitmap, uint8_t w, uint8_t h) {
  int8_t f, icons[NUMFLAKES][3];

  // Initialize 'snowflake' positions
  for(f=0; f< NUMFLAKES; f++) {
    icons[f][XPOS]   = random(1 - LOGO_WIDTH, display.width());
    icons[f][YPOS]   = -LOGO_HEIGHT;
    icons[f][DELTAY] = random(1, 6);
    Serial.print(F("x: "));
    Serial.print(icons[f][XPOS], DEC);
    Serial.print(F(" y: "));
    Serial.print(icons[f][YPOS], DEC);
    Serial.print(F(" dy: "));
    Serial.println(icons[f][DELTAY], DEC);
  }

  while(stby == 0) { // Loop until standby wake
    poll();
    display.clearDisplay(); // Clear the display buffer

    // Draw each snowflake:
    for(f=0; f< NUMFLAKES; f++) {
      display.drawBitmap(icons[f][XPOS], icons[f][YPOS], bitmap, w, h, WHITE);
    }

    display.display(); // Show the display buffer on the screen
    delay(200);        // Pause for 1/10 second

    // Then update coordinates of each flake...
    for(f=0; f< NUMFLAKES; f++) {
      icons[f][YPOS] += icons[f][DELTAY];
      // If snowflake is off the bottom of the screen...
      if (icons[f][YPOS] >= display.height()) {
        // Reinitialize to a random position, just off the top
        icons[f][XPOS]   = random(1 - LOGO_WIDTH, display.width());
        icons[f][YPOS]   = -LOGO_HEIGHT;
        icons[f][DELTAY] = random(1, 6);
      }
    }
  }
}
/**
 * Main program loop that calls the main program directives in turn 
 * @see stop()
 * @see poll()
 * @see relay()
 * @see printState()
 */
void loop() {
  //main program loop
  stop();
  poll();
  relay();
  printState();
}

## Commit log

2019-04-15 pinout and arduino
    [Ethernet Shield v2.0.brd, Ethernet Shield v2.0.sch, Relay shield.brd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]
2019-09-12 Updated code and added drawings
    [kkClave_Front_Panel v1.f3d, kkClave_Power_Panel v7.f3d]
2019-09-13 code RC1
    fished:
    Standby
    Holdown race
    Fan cont
    Light cont
2019-09-13 update comments
    [kkClave_Logic_Enclosure.f3d]
2019-10-01 Update arduino_sketch.ino
    commented code

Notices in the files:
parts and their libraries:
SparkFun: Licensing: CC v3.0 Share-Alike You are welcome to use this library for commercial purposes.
